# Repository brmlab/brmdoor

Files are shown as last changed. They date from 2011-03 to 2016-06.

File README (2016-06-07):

=== Brmdoor control software ===

brmd/ - integration hub that collects data from various sources and provides
unified reporting on IRC and web etc.
install dependecies:
  aptitude install git libimage-magick-perl liblogger-syslog-perl libdevice-serialport-perl\
    libpoe-perl libtie-ixhash-perl screen libpoe-component-server-http-perl libexpat1-dev\
    libxml-simple-perl libpoe-component-irc-perl arduino-mk
  cpan> install WWW::WolframAlpha

brmdoor/ - Arduino software

Project webpage: http://brmlab.cz/project/brmdoor

Note for PN532 version: if you want brmdoor to add card UID after "CARD"
message (not just nick), set printFullUID to true in brmdoor/brmdoor.ino.

==== Adding new UIDs to the database ====

There are two lists - the new proper and the old deperecated with truncated UIDs.
When adding, the new list is better place.

The new proper list is searched for UIDs first.

===== Using the new proper list - recommended =====

Edit the cardids_proper.h file and add your UID and nick to a new line, which
will become part of the ACLproper array. E.g. to add UID 04c24ce9ad2780 that is
7 bytes long and adding nick "voyeur1", add line:

  { 7, {0x04, 0xc2  0x4c, 0xe9, 0xad, 0x27, 0x80}, "voyeur1" },

===== Using the old broken truncated list - not recommended =====

Edit the cardids.h file. If the new card UID is 4 bytes long, e.g. 35b018d4,
compute BCC, which is xor of these four bytes (0x49 in this case). Then add

  { {0x00, 0x00, 0x35, 0xb0, 0x18, 0xd4, 0x49}, "mifare_classic_1" },

The first two bytes are magic bytes that originate in the old reader, just use
two zero bytes as above. The last byte is BCC we computed before. But you can
use zero, the software doesn't need it.

If the card UID is longer than 4 bytes (7 or 10 bytes), e.g. 04c24ce9ad2780,
discard last four bytes of the UID and prepend 0x88. Use this "newly" created
UID as if the card had only 4 byte UID, just like above.

  { {0x00, 0x00, 0x88, 0x04, 0xc2, 0x4c, 0x02}, "truncated_voyeur1" },

The old reader didn't support ISO14443 SELECT cascade 2 and 3. Hence the broken
UIDs.

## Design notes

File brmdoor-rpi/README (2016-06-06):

This is quick and dirty version of brmdoor that does not require Arduino, and runs only on Raspberry Pi.

This version of brmdoor requires:
- create user brmdoor, ~brmdoor/.screenrc
- create /etc/systemd/system/brmdoor.service in case systemd is used to autostart brmdoor service
- irssi configured according to ./irssi/config with loaded scripts from ./irssi/scripts
- libnfc-compatible smartcard reader
- libnfc installed
- create /etc/nfc/libnfc.conf using content from libnfc.conf supplied (otherwise nfc-list wouldnt find your NFC device)
- nfc-getcard.c compiled against libnfc (with -lnfc) and saved as "./nfc-getcard"
- to be running on RaspberryPi (or simillar with GPIO pins exported through /proc)
- variables in brmdoor-rpi.sh modified according to reality
- list of allowed cards in allowed.list in the correct format

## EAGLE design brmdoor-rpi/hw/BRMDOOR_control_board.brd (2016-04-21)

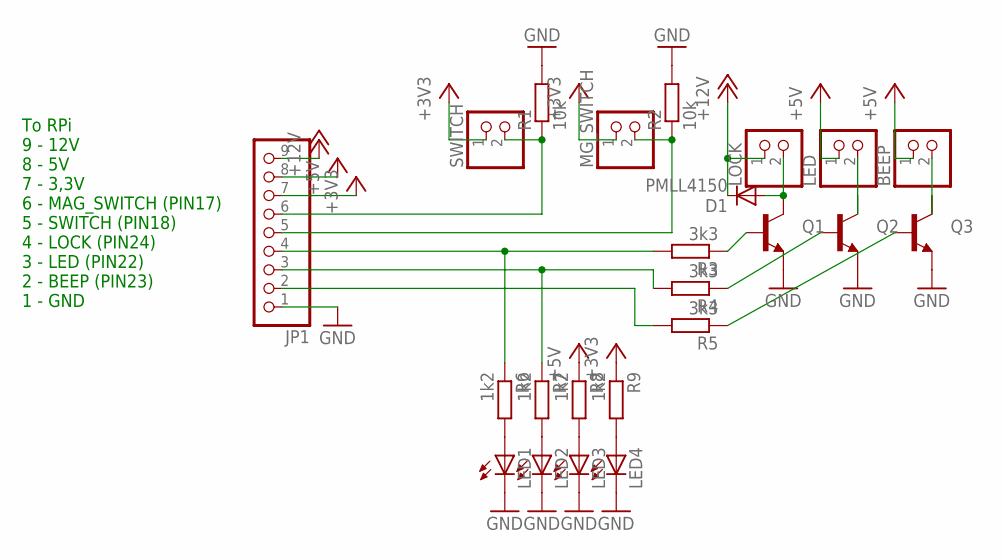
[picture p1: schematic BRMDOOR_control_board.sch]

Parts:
BEEP: PINHD-1X2; 1X02
D1: PMLL4150; SOD80C
JP1: PINHD-1X9; 1X09
LED: PINHD-1X2; 1X02
LED1, LED2, LED3, LED4: LEDKA-3528ASYC; KA-3528ASYC
LOCK: PINHD-1X2; 1X02
MG_SWITCH: PINHD-1X2; 1X02
Q1, Q2, Q3: TRANSISTOR_NPNSMD2; SOT223
R1, R2: 10k; M1206
R3, R4, R5: 3k3; M1206
R6, R7, R8, R9: 1k2; M1206
SWITCH: PINHD-1X2; 1X02

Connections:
+3V3: JP1.7, MG_SWITCH.1, R9.1, SWITCH.1
+5V: BEEP.1, JP1.8, LED.1, R8.1
+12V: D1.C, JP1.9, LOCK.1
GND: JP1.1, LED1.C, LED2.C, LED3.C, LED4.C, Q1.3 (E), Q2.3 (E), Q3.3 (E), R1.2, R2.2
unnamed: JP1.6, R1.1, SWITCH.2
unnamed: JP1.5, MG_SWITCH.2, R2.1
unnamed: Q1.1 (B), R3.1
unnamed: Q2.1 (B), R4.1
unnamed: Q3.1 (B), R5.1
unnamed: JP1.4, R3.2, R6.1
unnamed: JP1.3, R4.2, R7.1
unnamed: JP1.2, R5.2
unnamed: LED1.A, R6.2
unnamed: LED2.A, R7.2
unnamed: LED3.A, R8.2
unnamed: LED4.A, R9.2
unnamed: D1.A, LOCK.2, Q1.2 (C)
unnamed: LED.2, Q2.2 (C)
unnamed: BEEP.2, Q3.2 (C)

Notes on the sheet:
To RPi 9 - 12V 8 - 5V 7 - 3,3V 6 - MAG_SWITCH (PIN17) 5 - SWITCH (PIN18) 4 - LOCK (PIN24) 3 - LED (PIN22) 2 - BEEP (PIN23) 1 - GND

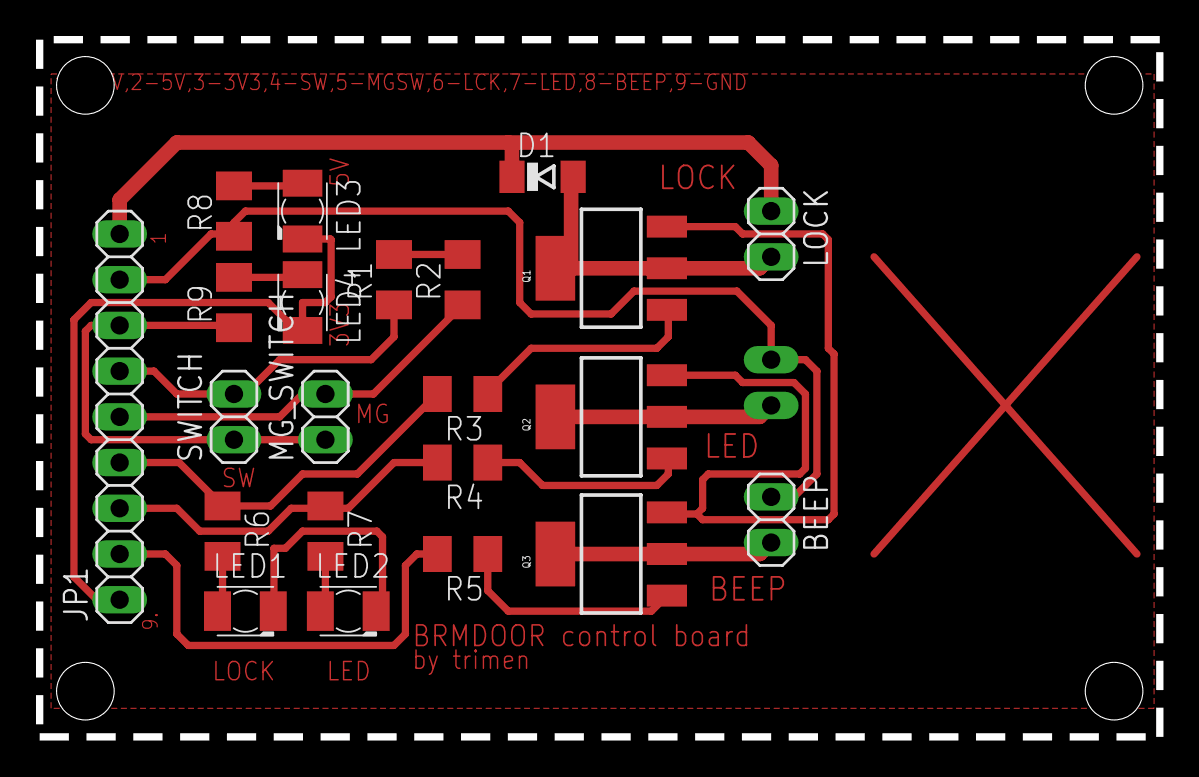
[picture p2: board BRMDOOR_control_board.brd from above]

Board: 2 copper layers, 62.2 x 38.7 mm, 23 parts (1 on the bottom side), 19 nets.

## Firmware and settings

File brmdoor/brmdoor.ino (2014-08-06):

// get file cardids.h from the Council section in our wiki!

#define MUSIC 1

#include <SoftwareSerial.h>
#include <Adafruit_PN532.h>

// pins
const int magnetPin = 10;
const int soundPin = 9; /* piezo in series with 100R */
const int statusLed = 8;
const int statusBtn = 7;
const int videoLed = 6;
const int videoBtn = 5;
const int doorLock = 4;
const int rfidRx = 3;
const int rfidTx = 2;

// Pins where Adafruit PN532 shield is connected.
// Note that these are the analog pins used in digital mode - no other pins
// were available.
const int PN532_SCK   = A3;
const int PN532_MOSI  = A2;
const int PN532_SS    = A1;
const int PN532_MISO  = A0;

// Set to true if you want to have correct UID printed in hex after CARD
// message into UART (case when card is known).
bool printFullUID = true;

// If set to true, will add string "proper" after the CARD message to signify
// that the UID was found in the proper ACL list.
bool printProper = true;

// Max retries to read card before timeout, 200 is around 1 second, 0xFF means
// wait forever (constitutes blocking read).
uint8_t pn532MaxRetries = 200;
bool pn532Working; //whether we have connected and working chip

int statusState = 0, statusStateOverride = 0;
int videoState = 0, videoStateOverride = 0;

/*!
 * The cardId is the same as you can see in CARD telnet message
 *
 * It's called broken, because we had broken reader that couldn't read 7-byte IDs.
 * I.e. the old reader could only use SELECT cascade 1, which begins with 0x88
 * cascading tag, thus we have only 3 bytes from 7-byte UIDs.
 *
 * So if we get a 7-byte ID, we must do "retarded search" for the 3-byte part.
 * If an ID in this struct contains 0x88 as third byte (index 2), it means it's
 * a card with 7 or 10 byte UID and begins with a cascading tag 0x88.
 * 
 * Currently the bytes seem to be:
 *
 * case of 4-byte UID:  0x00, 0x00, UID1, UID2, UID3, UID4, BCC
 * case of 7-byte UID:  0xFF, 0x00, 0x88, UID1, UID2, UID3, BCC
 * case of 10-byte UID: ??? I don't think I actually saw a real card with
 *                      10-byte UID, but it's in the NXP specs
 *
 */
typedef struct ACLdataBroken {
    byte cardId[7];
    const char *nick;
} ACLRecordBroken;

/*! 
 * List of ACLs included from a static array, see ACLRecordBroken for details.
 */
ACLRecordBroken ACL[] = {
/* The following include file contains lines like
 * { {0x12, 0x34, 0x56, 0x78, 0x9A, 0xBC, 0xDE}, "username" },
 */
#include "cardids.h"
};

/*! Structure for correct card UIDs */
typedef struct ACLdataProper {
    uint8_t uidLength;
    uint8_t uid[10];
    const char *nick;
} ACLRecordProper;

/*! 
 * List of ACLs with proper full card's UID, included from another file.
 *
 * Keep the last element of array having uidLength of 0 last, it's a
 * terminator (so that we don't have to do sizeof arithmetic and guesstimating
 * whether aliasing will break it or not).
 */
ACLRecordProper ACLproper[] = {
/* The following include file contains lines like
 * { 4, {0x35, 0xb0, 0x18, 0xd4}, "mifare_1" },
 * { 7, {0x04, 0xc2  0x4c, 0xe9, 0xad, 0x27, 0x80}, "ultralight_c" },
 *
 * Format of each array item is { UID_length, { UID_bytes }, nickname }
 */
#include "cardids_proper.h"
 { 0, {0x00}, "terminator, don't delete this element!" }
};

// Let's hope aliasing won't break this.
// OMG why not some proper structures?
#define ACL_COUNT (sizeof(ACL)/sizeof(ACLRecordBroken))

// ISO14443 cascading tag
#define CASCADING_TAG 0x88

// comSerial for communication with the host
#define comSerial Serial

// PN532 chip instance
Adafruit_PN532 nfc(PN532_SCK, PN532_MISO, PN532_MOSI, PN532_SS);

#if MUSIC

#include "pitches.h"

int melody_nak[] = { NOTE_G5, NOTE_G5, NOTE_G5, NOTE_DS5, NOTE_AS5, NOTE_G5, NOTE_DS5, NOTE_AS5, NOTE_G5};
int noteDurations_nak[] = { 330, 330, 330, 250, 120, 330, 250, 120, 500 };

int melody_ack[] = { NOTE_D6, NOTE_A6, NOTE_C7, NOTE_A6 };
int noteDurations_ack[] = { 120, 500, 120, 500 };

int melody_alarm[] = { NOTE_D6, NOTE_F6, NOTE_D6, NOTE_F6 };
int noteDurations_alarm[] = { 700, 700, 700, 700 };

void toneManual(int pin, int frequency, int duration)
{
  unsigned long period = 1000000/frequency;
  unsigned long length;
  boolean state = false;
  for (length = 0; length < (long) duration * 1000; length += period) {
    state = !state;
    digitalWrite(pin, state);
    /* The 50uS correspond to the time the rest of the loop body takes.
     * It seems about right, but has not been tuned precisely for
     * a 16MHz ATMega. */
    delayMicroseconds(period - 50);
    //comSerial.print(pin, DEC); comSerial.print(state, DEC); comSerial.write(" "); comSerial.print(period); comSerial.write(" "); comSerial.print(length); comSerial.write("\n");
  }
}

void playMelody(int *melody, int *noteDurations, int dcoef, int notes)
{
  int i;
  for (i = 0; i < notes; i++) {
    // comSerial.print(melody[i]); comSerial.write(" "); comSerial.print(noteDurations[i]); comSerial.write("\n");
    toneManual(soundPin, melody[i], noteDurations[i]);

    delay(noteDurations[i] * dcoef/10);
  }
}

void playMelodyAck()
{ playMelody(melody_ack, noteDurations_ack, 6, sizeof(melody_ack)/sizeof(melody_ack[0])); }
void playMelodyNak()
{ playMelody(melody_nak, noteDurations_nak, 6, sizeof(melody_nak)/sizeof(melody_nak[0])); }
void playMelodyAlarm()
{ playMelody(melody_alarm, noteDurations_alarm, 1, sizeof(melody_alarm)/sizeof(melody_alarm[0])); }


#else

void playMelodyAck()
{}
void playMelodyNak()
{}
void playMelodyAlarm()
{}

#endif

// opens door for "ms" milliseconds
void openDoorForTime(int ms)
{
  digitalWrite(doorLock, HIGH);
  playMelodyAck();
  delay(ms);
  digitalWrite(doorLock, LOW);
}

/*!
 * Will search for given card UID in the borken ACL list with truncated UIDs.
 * 
 * @param uid UID of the card read
 * @param length length of the UID in bytes
 * @param acls list of ACLs in the old b0rken form
 * @param count of ACLs in the above array
 * @returns index into acls if found or -1 if not found
 */
int retardedACLSearch(const uint8_t *uid, uint8_t length, const struct ACLdataBroken *acls, int aclCount)
{
    int idx = -1;

    for(int i=0; i<aclCount; i++) {
        const ACLRecordBroken& acl = acls[i];

        // Look for ISO14443 cascading tag 0x88 in third byte of the UID.
        // If it's present, then the UID has been truncated - only 3 bytes
        // are correct. Otherwise we got correct 4 byte UID.
        if (acl.cardId[2] == CASCADING_TAG) { // truncated UID
            if (memcmp(acl.cardId+3, uid, 3) == 0) {
                idx = i;
                break;
            }
        } else { // full 4-byte UID
            if (memcmp(acl.cardId+2, uid, 4) == 0) {
                idx = i;
                break;
            }
        }
    }

    return idx;
}

/*!
 * Will search for given card UID in the proper ACL list.
 * 
 * @param uid UID of the card read
 * @param length length of the UID in bytes
 * @param acls list of proper ACLs (must contain the terminator as last element, see typedef above)
 * @returns index into acls if found or -1 if not found
 */
int properACLSearch(const uint8_t *uid, uint8_t length, const struct ACLdataProper *acls)
{
    int idx = -1;

    for(int i=0; ; i++) {
        const ACLRecordProper& acl = acls[i];

        if (acl.uidLength == 0) {
            break; // reached terminator, no more elements
        }

        if (length != acl.uidLength) {
            continue;
        }

        if (memcmp(uid, acl.uid, length) == 0) {
            idx = i;
            break;
        }
    }

    return idx;
}

/*! Writes given UID encoded in hex to the serial specified. */
void serialWriteUIDHex(const uint8_t *uid, uint8_t length)
{
    for (int i=0; i<length; i++) {
        // why the fuck doesn't it have printf by default?
        if (uid[i] < 0x10) {
            comSerial.print("0");
        }
        comSerial.print(uid[i], HEX);
    }
}

/*! Returns true iff we could read a card's UID.
 * That card UID is then looked up in the ACL array and response is sent
 * via UART to controlling computer (Raspberry, etc).
 *
 * Opens door for 5 seconds if the UID matched something in ACL array.
 *
 * Note: PN532 can read multiple cards in its field, but this is not supported
 * here (not necessary). The reader will pick one if there's more of them.
 */
bool readCardPN532()
{
    uint8_t uid[10] = {0};
    uint8_t uidLength = 0;
    bool success;
    bool proper = false; // true will indicate we found UID in new non-borken ACL list
    int aclIdx = -1;

    if (!pn532Working) {
        comSerial.write("NOCARD\n");
        return false;
    }

    // read from PN532, change according to cardids, write result to comSerial
    success = nfc.readPassiveTargetID(PN532_MIFARE_ISO14443A, &uid[0], &uidLength);

    if (!success) {
        // no card in reader field
        comSerial.write("NOCARD\n");
        return false;
    }

    // try searching in proper ACL list first
    aclIdx = properACLSearch(uid, uidLength, ACLproper);

    if (aclIdx >= 0) {
        proper = true;
    } else {
        // search for card UID in b0rken ACL database
        aclIdx = retardedACLSearch(uid, uidLength, ACL, ACL_COUNT);
    }

    if (aclIdx < 0) {
        // unknown card ID
        comSerial.write("CARD UNKNOWN ");
        serialWriteUIDHex(uid, uidLength);
        comSerial.write("\n");
        playMelodyNak();
        delay(750);
        return false;
    }

    // OK we got some known card, print its nick from respective ACL array
    comSerial.write("CARD ");
    comSerial.write(proper ? ACLproper[aclIdx].nick : ACL[aclIdx].nick);

    if (printFullUID) {
        comSerial.write(" ");
        serialWriteUIDHex(uid, uidLength);
    }

    // for debugging purposes - to know that we got the UID from proper ACL list
    if (printProper && proper) {
        comSerial.write(" proper");
    }

    comSerial.write("\n");

    openDoorForTime(5000);
    
    return true;
}

/*! Set status led according to status, delat a bit. */
void statusUpdate()
{
  delay(100);
  digitalWrite(statusLed, statusState);
  delay(150);
}

void readSerial()
{
  if (comSerial.available()) {
    unsigned char cmd = comSerial.read();
    unsigned char data = comSerial.read();
    switch (cmd) {
      case 's': statusState = data - '0'; statusStateOverride = 1; break;
      case 'v': videoState = data - '0'; videoStateOverride = 1; break;
      case 'a': playMelodyAlarm(); /* data ignored */ break;
    }
  }
}

void setup()
{
  pinMode(magnetPin, INPUT);
  digitalWrite(magnetPin, HIGH);
  pinMode(doorLock, OUTPUT);
  pinMode(soundPin, OUTPUT);
  pinMode(statusLed, OUTPUT);
  pinMode(videoLed, OUTPUT);
  pinMode(statusBtn, INPUT);
  digitalWrite(statusBtn, HIGH);
  pinMode(videoBtn, INPUT);
  digitalWrite(videoBtn, HIGH);
  comSerial.begin(9600);

  nfc.begin();
  uint32_t versiondata = nfc.getFirmwareVersion();
  if (! versiondata) {
    comSerial.write("CARD READER BROKEN\n");
    pn532Working = false;
  } else {
    nfc.SAMConfig();
    nfc.setPassiveActivationRetries(pn532MaxRetries);
    pn532Working = true;
  }
}

void loop()
{
  /* Check buttons. */
  int statusStateNew = !digitalRead(statusBtn);
  int videoStateNew = !digitalRead(videoBtn);
  /* Cancel override if button is in same state as official state. */
  if (statusState == statusStateNew) statusStateOverride = 0;
  if (videoState == videoStateNew) videoStateOverride = 0;
  /* Update state based on buttons and override. */
  if (!statusStateOverride) statusState = statusStateNew;
  if (!videoStateOverride) videoState = videoStateNew;
  
  int doorOpen = digitalRead(magnetPin);

  digitalWrite(statusLed, !statusState);
  digitalWrite(videoLed, videoState);

  comSerial.print(statusState, DEC); comSerial.write(" ");
  comSerial.print(videoState, DEC); comSerial.write(" ");
  comSerial.print(doorOpen, DEC); comSerial.write(" ");

  statusUpdate();

  readCardPN532();
  readSerial();
}

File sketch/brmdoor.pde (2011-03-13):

// get file cardids.h from the Council section in our wiki!

#define MUSIC 1

#include <NewSoftSerial.h>

// pins
const int soundPin = 9; /* piezo in series with 100R */
const int statusLed = 8;
const int statusBtn = 7;
const int videoLed = 6;
const int videoBtn = 5;
const int doorLock = 4;
const int rfidRx = 3;
const int rfidTx = 2;

int statusState = 0;
int videoState = 0;

// cardId is the same as you can see in CARD telnet message
struct ACLdata {
  byte cardId[7];
  char *nick;
} ACL[] = {
// the following include file contains lines like
// { {0x12, 0x34, 0x56, 0x78, 0x9A, 0xBC, 0xDE}, "username" },
#include "cardids.h"
};

// comSerial for communication with the host
#define comSerial Serial

// rfidSerial for communication with the RFID reader
NewSoftSerial rfidSerial(rfidTx, rfidRx);

#if MUSIC

#include "pitches.h"

int melody_nak[] = { NOTE_G5, NOTE_G5, NOTE_G5, NOTE_DS5, NOTE_AS5, NOTE_G5, NOTE_DS5, NOTE_AS5, NOTE_G5};
int noteDurations_nak[] = { 330, 330, 330, 250, 120, 330, 250, 120, 500 };

int melody_ack[] = { NOTE_D6, NOTE_A6, NOTE_C7, NOTE_A6 };
int noteDurations_ack[] = { 120, 500, 120, 500 };

void toneManual(int pin, int frequency, int duration)
{
  unsigned long period = 1000000/frequency;
  unsigned long length;
  boolean state = false;
  for (length = 0; length < (long) duration * 1000; length += period) {
    state = !state;
    digitalWrite(pin, state);
    /* The 50uS correspond to the time the rest of the loop body takes.
     * It seems about right, but has not been tuned precisely for
     * a 16MHz ATMega. */
    delayMicroseconds(period - 50);
    //comSerial.print(pin, DEC); comSerial.print(state, DEC); comSerial.write(" "); comSerial.print(period); comSerial.write(" "); comSerial.print(length); comSerial.write("\n");
  }
}

void playMelody(int *melody, int *noteDurations, int notes)
{
  int i;
  for (i = 0; i < notes; i++) {
    // comSerial.print(melody[i]); comSerial.write(" "); comSerial.print(noteDurations[i]); comSerial.write("\n");
    toneManual(soundPin, melody[i], noteDurations[i]);

    delay(noteDurations[i] * 6/10);
  }
}

void playMelodyAck()
{ playMelody(melody_ack, noteDurations_ack, sizeof(melody_ack)/sizeof(melody_ack[0])); }
void playMelodyNak()
{ playMelody(melody_nak, noteDurations_nak, sizeof(melody_nak)/sizeof(melody_nak[0])); }

#else

void playMelodyAck()
{}
void playMelodyNak()
{}

#endif

// opens door for "ms" milliseconds
void openDoorForTime(int ms)
{
  digitalWrite(doorLock, HIGH);
  playMelodyAck();
  delay(ms);
  digitalWrite(doorLock, LOW);
}

void readCard()
{
  byte RequestCardStatus[] = { 0xAA, 0x00, 0x03, 0x25, 0x26, 0x00, 0x00, 0xBB };
  byte NoCardResponse[] = { 0xAA, 0x00, 0x02, 0x01, 0x83, 0x80, 0xBB };
  byte buf[16];
  int i;

  // write query to serial
  for (i = 0; i < 8; i++)
    rfidSerial.print(RequestCardStatus[i]);
  // wait for the result, while reblinking
  delay(100);
  digitalWrite(statusLed, statusState);
  delay(150);

  // read input from serial into the buffer
  i = 0;
  while (rfidSerial.available() > 0) {
    if (i < sizeof(buf)) {
      buf[i] = rfidSerial.read();
    }
    ++i;
  }

  // no card is detected
  if (!memcmp(buf, NoCardResponse, 7)) {
    comSerial.write("NOCARD\n");
  }

  // card detected - message has form AA0006xxxxxxxxxxxxxxBB where xxx... is the card ID
  if (buf[0] == 0xAA && buf[1] == 0x00 && buf[2] == 0x06 && buf[10] == 0xBB) {
    bool known = false;
    // go through ACL
    for (int i = 0; i < sizeof(ACL)/sizeof(ACL[0]); ++i) {
      // if there is a match - print known card ...
      if (!memcmp(ACL[i].cardId, buf+3, 7)) {
        known = true;
        comSerial.write("CARD ");
        comSerial.write(ACL[i].nick);
        comSerial.write("\n");
        // ... and open door for 5s
        openDoorForTime(5000);
        break;
      }
    }
    // card was not found in the ACL
    if (!known) {
      comSerial.write("CARD UNKNOWN ");
      for (int i = 0; i < 7; ++i) {
        if (buf[i+3] < 0xF) comSerial.write("0");
        comSerial.print(buf[i+3], HEX);
      }
      comSerial.write("\n");
      playMelodyNak();
    }
  }
  // make cycle interval 1s
  delay(750);
}

void setup()
{
  pinMode(doorLock, OUTPUT);
  pinMode(soundPin, OUTPUT);
  pinMode(statusLed, OUTPUT);
  pinMode(videoLed, OUTPUT);
  pinMode(statusBtn, INPUT);
  digitalWrite(statusBtn, HIGH);
  pinMode(videoBtn, INPUT);
  digitalWrite(videoBtn, HIGH);
  rfidSerial.begin(9600);
  comSerial.begin(9600);
}

void loop()
{
  statusState = !digitalRead(statusBtn);
  videoState = !digitalRead(videoBtn);
  digitalWrite(statusLed, !statusState); // will be turned back in readCard()
  digitalWrite(videoLed, videoState);
  comSerial.print(statusState, DEC); comSerial.write(" ");
  comSerial.print(videoState, DEC); comSerial.write(" ");
  readCard();
}

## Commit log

2011-03-09 Replace brmdoor.php by full-fledged universal hub script brmd
    brmd should handle various kinds of brmlab-related events (brmdoor
    unlocks, status panel events, wiki updates) and provide central place
    to handle them, with unified interface (web and IRC).
    Currently, all of this should be implemented, except wiki updates
    handling. But the script is still a bit rudimentary; some TODO items
    are mentioned in the TODO file.
2011-03-09 add arduino sketch
2011-03-16 small fixes, add NewSoftSerial lib
    [brmdoor.pde]
2011-04-26 brmd: Support for manual status override using web button
2011-05-01 brmd.pl web_brmstatus_html: Change input button to submit
2011-05-01 brmd: Allow device filename override on commandline
2011-05-03 print also url of videostream
2011-05-03 brmd: Switch streaming on brmvid when record switch is pressed
2011-05-12 brmd: $device -> $devdoor
2011-05-17 brmd: Update default device names to use by-id paths
2011-08-30 Sketch: Fix reading new video/status state
    [brmdoor.pde]
2011-08-30 Fix manual status change desyncing arduino
2011-10-18 Sketch: Fix card number output
    [brmdoor.pde]
2011-10-18 Sketch: Fix override over serial
    [brmdoor.pde]
2011-10-18 Track dooropen ajar/shut state using a magnetic sensor, log verbosely for now
2011-10-20 brmd alert condition: Consider dangerous opens also in case of status manual override active
2013-06-17 README.raspberry added
2013-06-18 Makefile: arduino-mk thingie
2013-06-27 Make it working with latest Arduino
2014-03-25 Rewritten to use PN532 reader over SPI
2014-03-25 Note about printFullUID variable
2014-03-25 Printing UIDs enabled by default in CARD message
2014-03-25 Changed default board ID since the board was physically changed
2014-03-26 Added sample card array definitions
2014-12-02 ARDUINO_PORT change

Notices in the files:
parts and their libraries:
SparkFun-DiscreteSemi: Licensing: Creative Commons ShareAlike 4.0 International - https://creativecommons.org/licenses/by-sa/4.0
